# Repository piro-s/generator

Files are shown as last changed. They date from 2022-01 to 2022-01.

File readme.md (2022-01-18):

### generator  [OnHold]

#### Description device:  
The pulse generator, implemented on STM32, can generate:  
1. continuous pulse generation;  
2. generation of pulse bursts.  

Init mode:
- width - 1 us;  
- period - 10 us;  
- pack period - 100 us;  
- number of impulses - 5.  

Max number of impulses in package - 2048.  
Min pulse width 100 ns.  
Control from a computer via RS-232 (J8) interface or via UART-USB adapter (J6).  
The development of the device is suspended, the plans are:  
- firmware for analog channel;  
- saving data to a separate EEPROM (scheme and firmware);  
- firmware for LCD and keyboard;
- new version of the case.  

#### PC program description:
The program allows you to customize the set values for the generator.  
For use:  
- linux: run generator_pyGui.py  
- windows: run dist/generator_pyGui.exe  

Setup:  
1. Select the COM port to which the device is connected from the drop-down list:  
1_select  
2. By default, the generator runs in init mode. The current parameters are  
written in the current field. By pressing the button "Get parameters" you can  
get the current set values.  
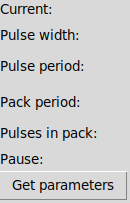
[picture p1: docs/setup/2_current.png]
2_current
  
If there is no data exchange with the generator, then there will be dashes in  
this field, there will also be errors in the log field.  
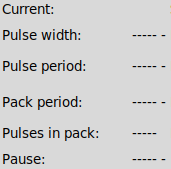
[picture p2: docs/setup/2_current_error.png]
2_current_error
  
3. The generator parameters are set in order, that is, the pulse duration and  
its period, the burst period (set in any case, even if not needed), the number  
of pulses are set separately, if the number of pulses is 0, then there will be  
a constant generation of pulses, without a burst.  
The name of the parameter is signed in the figure:  
3_setup  
If something is entered incorrectly, or some other error occurs, everything  
will be displayed in the log field.  
3_error  
4. If the wrong COM port was selected, then you can switch to the "Setup" tab,  
4_setup  
select "Disconnect", click "Refresh", select the required COM port from the  
drop-down list, and click the "Connect" button, you can go back to the  
"Impulse" tab.  

The protocol for data exchange between the device and the PC is  
[here](https://htmlpreview.github.io/?https://github.com/piro-s/generator/blob/master/docs/protocol.html).  

#### Scheme  
[scheme_v3.2_pdf](docs/scheme/scheme_v3.2.pdf)  

#### Case  
Prototype case for v3.2 generator board (case will fit next versions).  
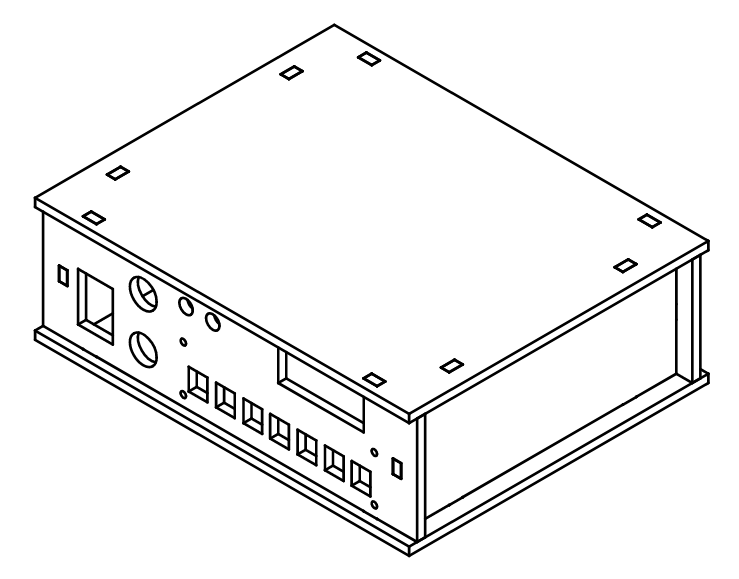
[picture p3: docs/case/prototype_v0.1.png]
prototype_v0_1
  
Errors:  
- the two diagonal posts interfere with the connectors.

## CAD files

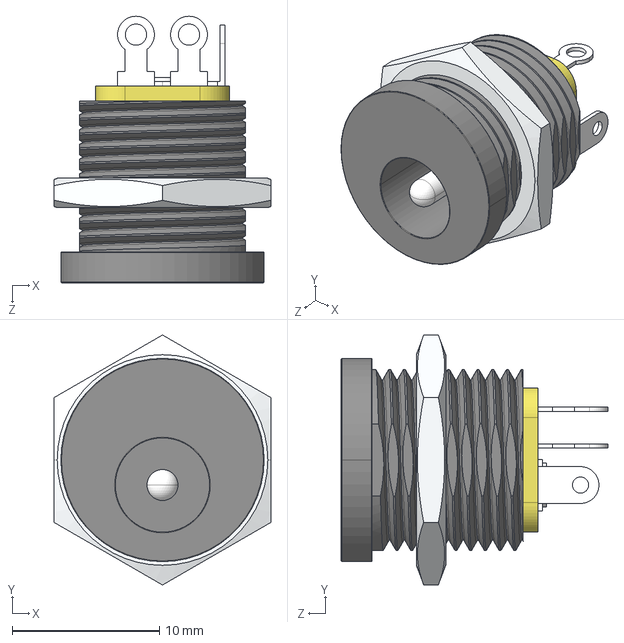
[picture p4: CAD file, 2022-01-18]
case/ASM, Adafruit 5.5 x 2.1 Coaxial DC Panel Mount Power Jack (PN 610).STEP
14.7 x 17.0 x 18.1 mm
Adafruit 5.5 x 2.1 DC Coax Panel Mount Power Jack (PN 601)_default
M12.5x1 Panel Nut_default

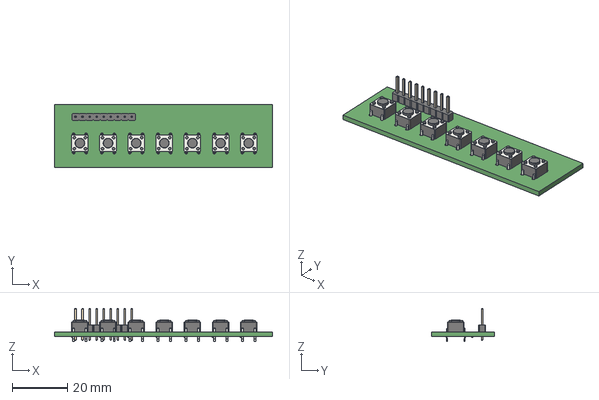
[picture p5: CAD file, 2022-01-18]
case/mini_keyboard.step
78.7 x 22.7 x 12.0 mm

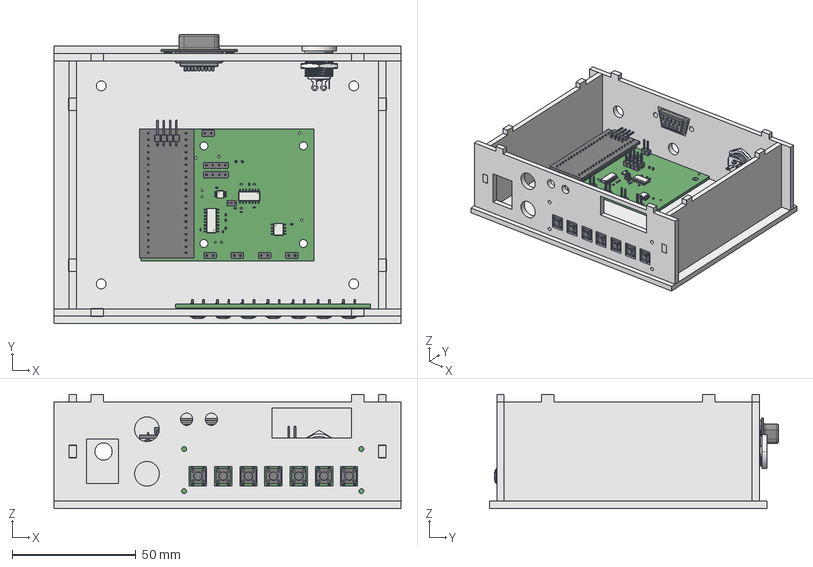
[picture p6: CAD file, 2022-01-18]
case/generator_v3.2.FCStd
140.0 x 116.7 x 46.0 mm
FRONT
RIGHT
BACK
LEFT
Adafruit 5.5 x 2.1 DC Coax Panel Mount Power Jack (PN 601)_default
M12.5x1 Panel Nut_default
D-Sub9 Female Connector with Solder Cups
BOTTOM

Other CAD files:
case/generator_v3.2.dxf

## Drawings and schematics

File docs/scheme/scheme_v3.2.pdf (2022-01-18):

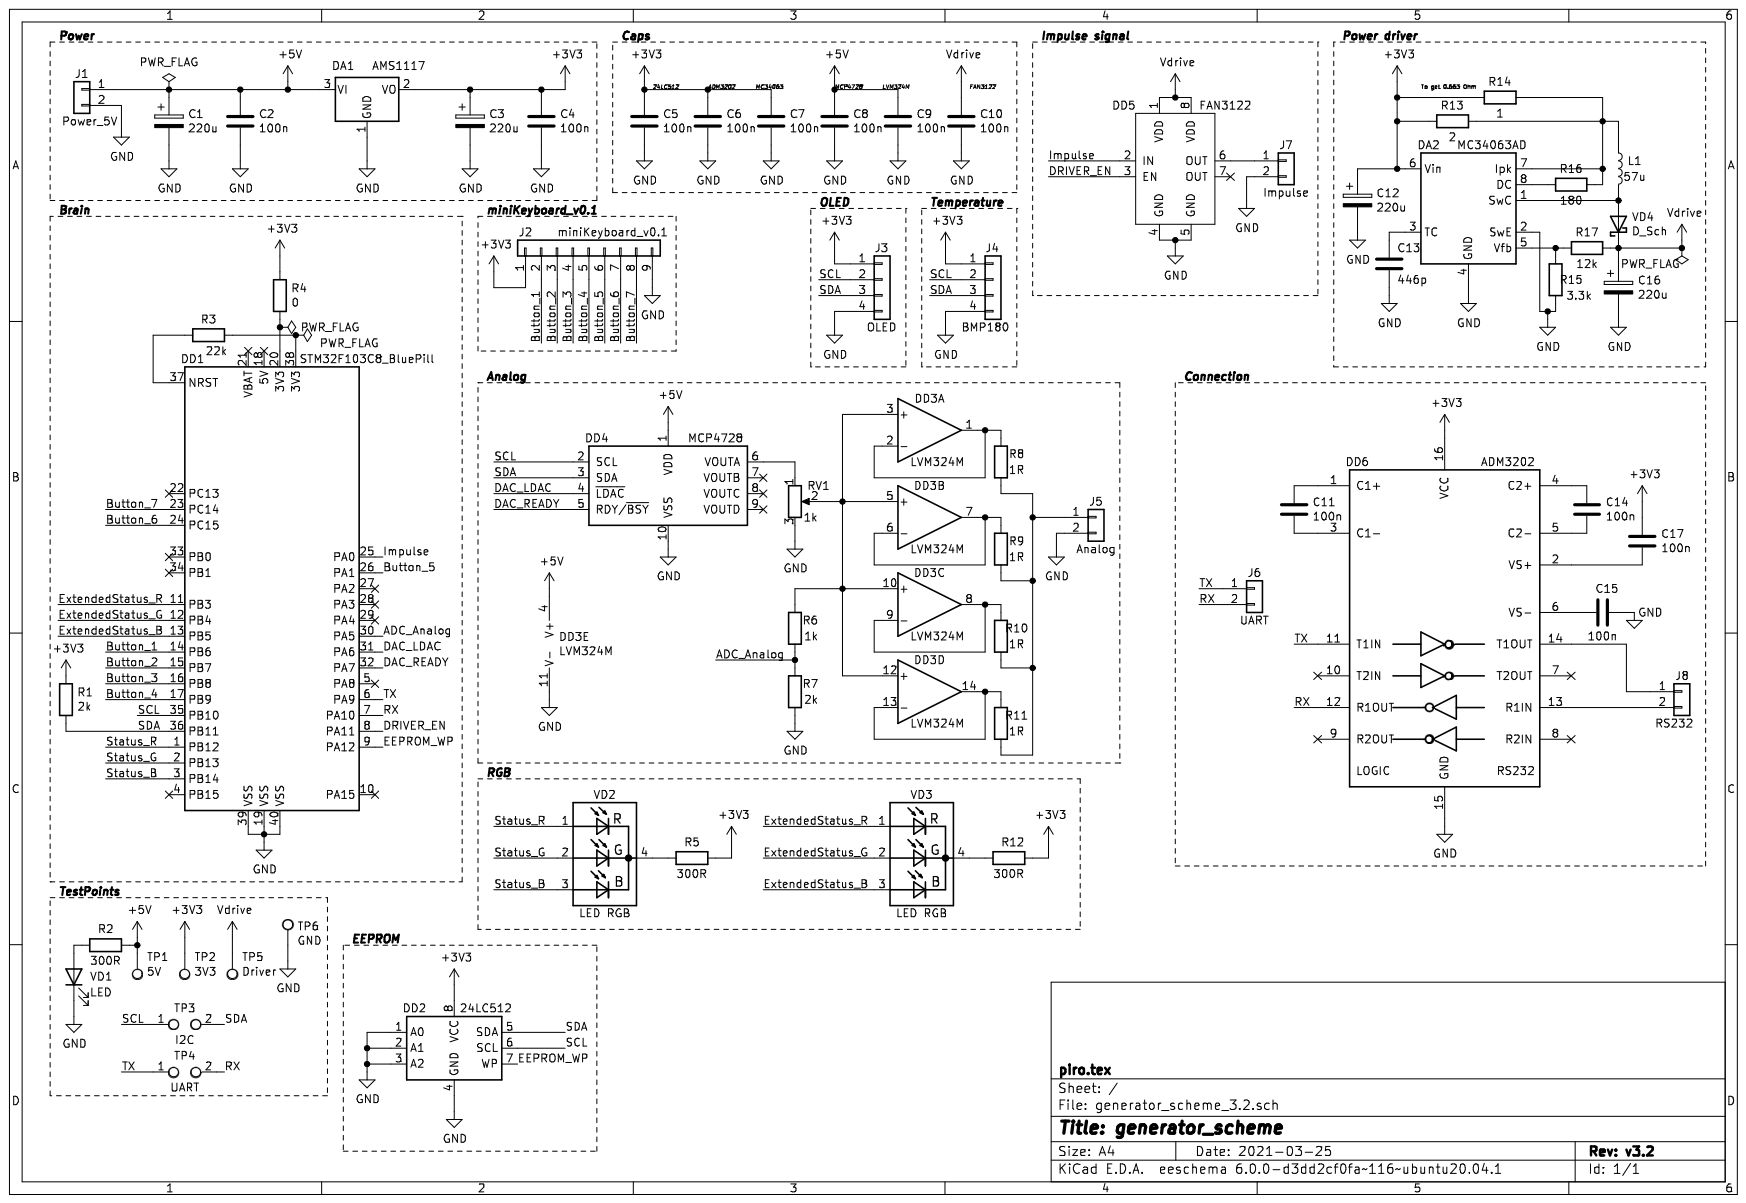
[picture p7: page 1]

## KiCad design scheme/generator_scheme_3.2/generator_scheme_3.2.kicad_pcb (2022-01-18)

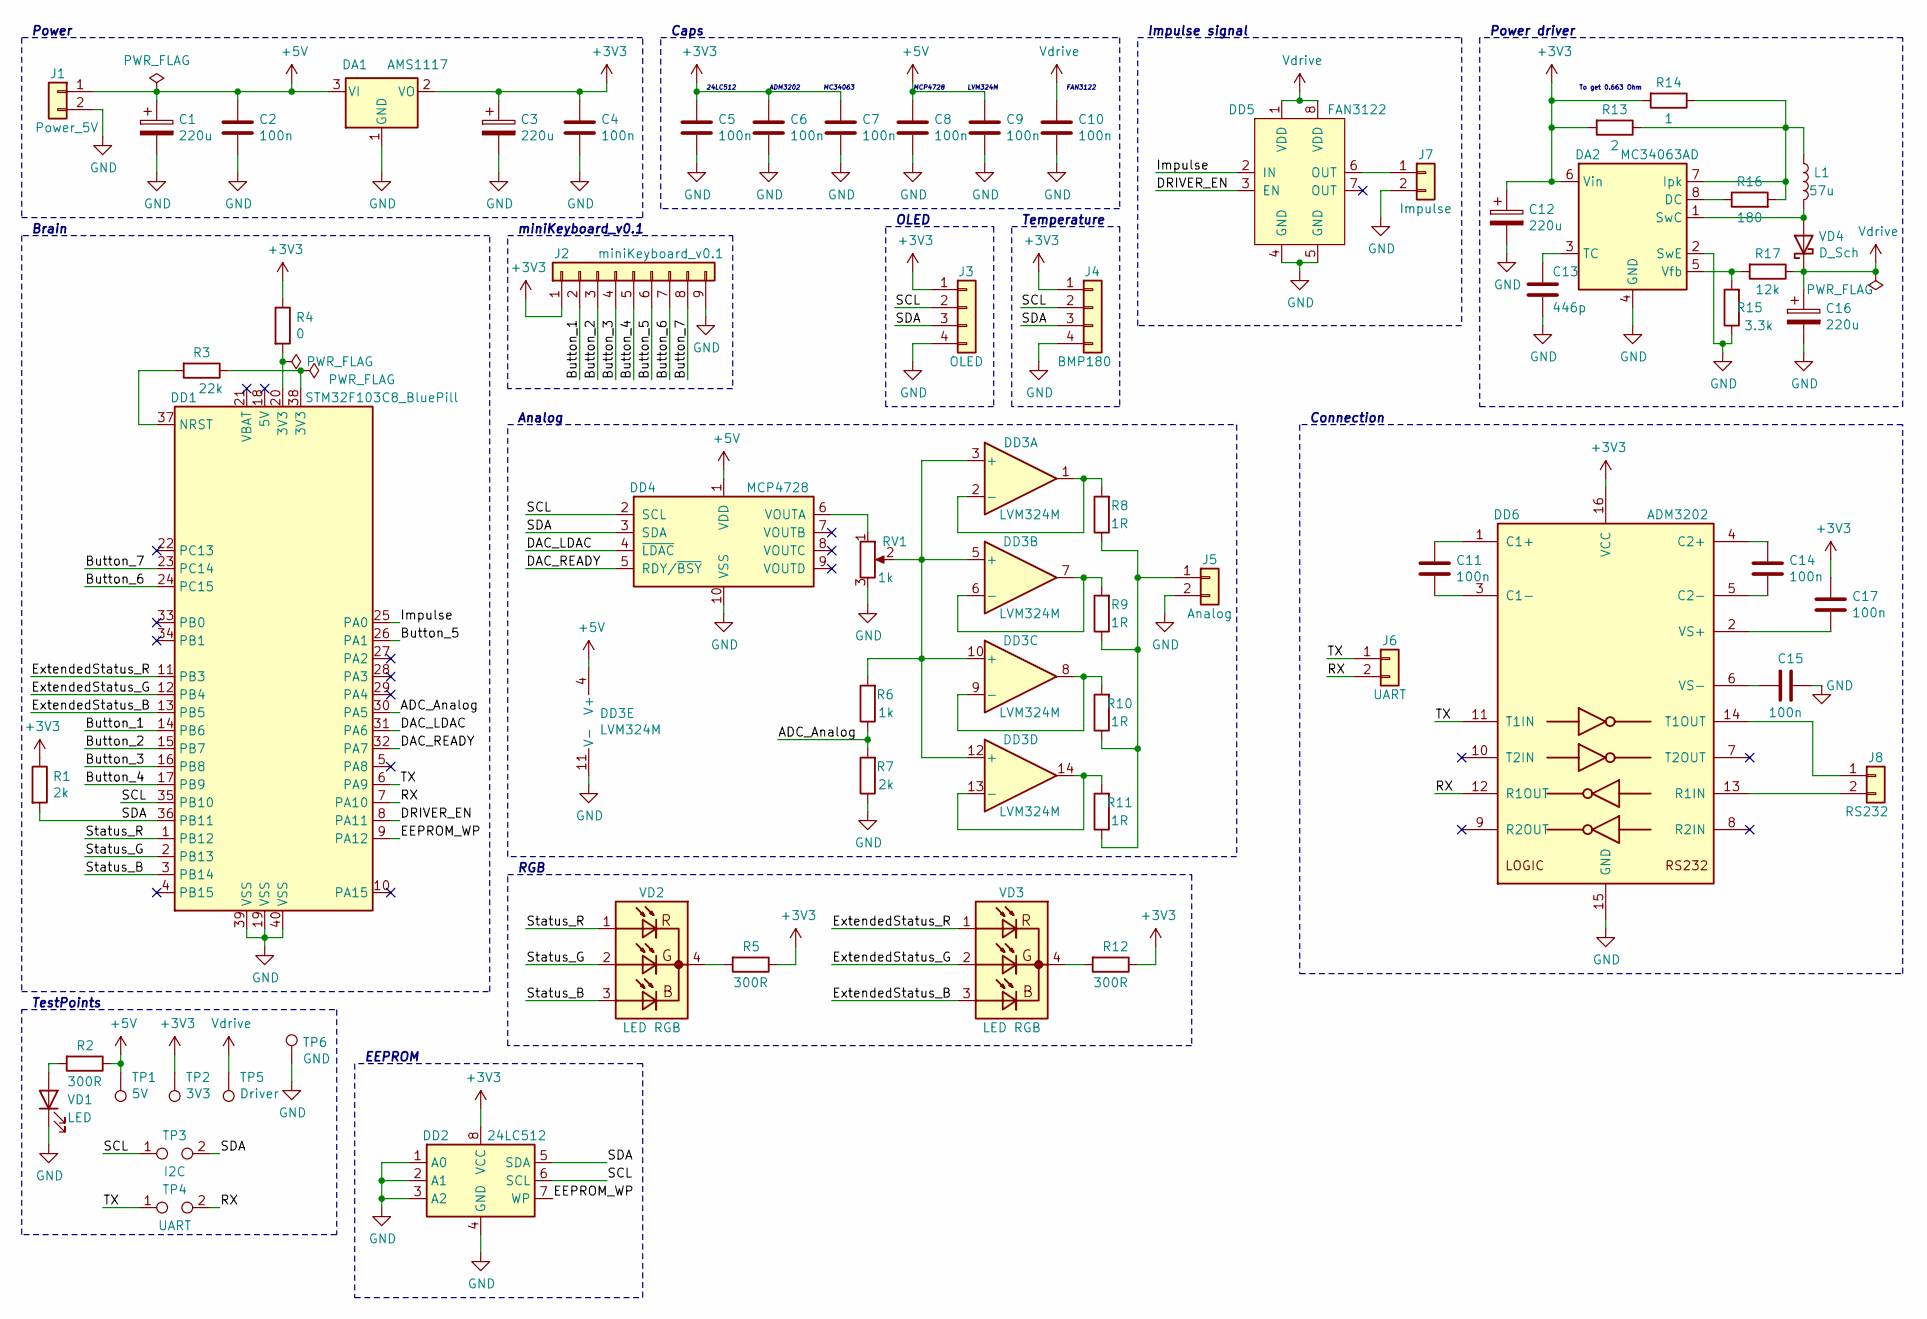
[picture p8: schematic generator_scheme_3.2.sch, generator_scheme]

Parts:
C1, C3, C12, C16: 220u; CP_EIA-7260-15_AVX-R_Pad2.68x6.30mm_HandSolder
C2, C4, C5, C6, C7, C8, C9, C10, C11, C14, C15, C17: 100n; C_0402_1005Metric
C13: 446p; C_0402_1005Metric
DA1: AMS1117; SOT-223-3_TabPin2
DA2: MC34063AD; SOIC-8_3.9x4.9mm_P1.27mm
DD1: STM32F103C8_BluePill
DD2: 24LC512; SOIC-8_3.9x4.9mm_P1.27mm
DD3: LVM324M; SOIC-14_3.9x8.7mm_P1.27mm
DD4: MCP4728; MSOP-10_3x3mm_P0.5mm
DD5: FAN3122; SOIC-8_3.9x4.9mm_P1.27mm
DD6: ADM3202; SO-16_3.9x9.9mm_P1.27mm
J1: Power_5V; PinHeader_1x02_P2.54mm_Vertical
J2: miniKeyboard_v0.1; PinSocket_1x09_P2.54mm_Vertical
J3: OLED; PinHeader_1x04_P2.54mm_Vertical
J4: BMP180; PinHeader_1x04_P2.54mm_Vertical
J5: Analog; PinHeader_1x02_P2.54mm_Vertical
J6: UART; PinHeader_1x02_P2.54mm_Vertical
J7: Impulse; PinHeader_1x02_P2.54mm_Vertical
J8: RS232; PinHeader_1x02_P2.54mm_Vertical
L1: 57u; L_7.3x7.3_H4.5
R1, R7: 2k; R_0402_1005Metric
R2, R5, R12: 300R; R_0402_1005Metric
R3: 22k; R_0402_1005Metric
R4: 0; R_0402_1005Metric
R6: 1k; R_0402_1005Metric
R8, R9, R10, R11: 1R; R_0402_1005Metric
R13: 2; R_0402_1005Metric
R14: 1; R_0402_1005Metric
R15: 3.3k; R_0402_1005Metric
R16: 180; R_0402_1005Metric
R17: 12k; R_0402_1005Metric
RV1: 1k; PinHeader_1x03_P1.27mm_Vertical
TP1: 5V; TestPoint_Keystone_5000-5004_Miniature
TP2: 3V3; TestPoint_Keystone_5000-5004_Miniature
TP3: I2C; TestPoint_2Pads_Pitch2.54mm_Drill0.8mm
TP4: UART; TestPoint_2Pads_Pitch2.54mm_Drill0.8mm
TP5: Driver; TestPoint_Keystone_5000-5004_Miniature
TP6: GND; TestPoint_Keystone_5000-5004_Miniature
VD1: LED; PinHeader_1x02_P2.54mm_Vertical
VD2, VD3: LED RGB; PinHeader_1x04_P1.27mm_Vertical
VD4: D_Sch; D_0603_1608Metric

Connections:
+3V3: C3.1, C4.1, C5.1, C6.1, C7.1, C12.1, C17.1, DA1.2 (VO), DA2.6 (Vin), DD2.8 (VCC), DD6.16 (VCC), J2.1, J3.1, J4.1, R1.1, R4.1, R5.1, R12.1, R13.2, R14.2, TP2.1
+5V: C1.1, C2.1, C8.1, C9.1, DA1.3 (VI), DD3.4 (V+), DD4.1 (VDD), J1.1, R2.1, TP1.1
/ADC_Analog: DD1.30 (PA5), R6.1, R7.2
/Button_1: DD1.14 (PB6), J2.2
/Button_2: DD1.15 (PB7), J2.3
/Button_3: DD1.16 (PB8), J2.4
/Button_4: DD1.17 (PB9), J2.5
/Button_5: DD1.26 (PA1), J2.6
/Button_6: DD1.24 (PC15), J2.7
/Button_7: DD1.23 (PC14), J2.8
/DAC_LDAC: DD1.31 (PA6), DD4.4 (~LDAC)
/DAC_READY: DD1.32 (PA7), DD4.5 (RDY/~BSY)
/DRIVER_EN: DD1.8 (PA11), DD5.3 (EN)
/EEPROM_WP: DD1.9 (PA12), DD2.7 (WP)
/ExtendedStatus_B: DD1.13 (PB5), VD3.3 (AB)
/ExtendedStatus_G: DD1.12 (PB4), VD3.2 (AG)
/ExtendedStatus_R: DD1.11 (PB3), VD3.1 (AR)
/Impulse: DD1.25 (PA0), DD5.2 (IN)
/RX: DD1.7 (PA10), DD6.12 (R1OUT), J6.2, TP4.2
/SCL: DD1.35 (PB10), DD2.6 (SCL), DD4.2 (SCL), J3.2, J4.2, TP3.1
/SDA: DD1.36 (PB11), DD2.5 (SDA), DD4.3 (SDA), J3.3, J4.3, R1.2, TP3.2
/Status_B: DD1.3 (PB14), VD2.3 (AB)
/Status_G: DD1.2 (PB13), VD2.2 (AG)
/Status_R: DD1.1 (PB12), VD2.1 (AR)
/TX: DD1.6 (PA9), DD6.11 (T1IN), J6.1, TP4.1
GND: C1.2, C2.2, C3.2, C4.2, C5.2, C6.2, C7.2, C8.2, C9.2, C10.2, C12.2, C13.2, C15.1, C16.2, DA1.1 (GND), DA2.2 (SwE), DA2.4 (GND), DD1.19 (VSS), DD1.39 (VSS), DD1.40 (VSS), DD2.1 (A0), DD2.2 (A1), DD2.3 (A2), DD2.4 (GND), DD3.11 (V-), DD4.10 (VSS), DD5.4 (GND), DD5.5 (GND), DD6.15 (GND), J1.2, J2.9, J3.4, J4.4, J5.2, J7.2, R7.1, R15.1, RV1.3, TP6.1, VD1.1 (K)
unnamed: C11.1, DD6.1 (C1+)
unnamed: C11.2, DD6.3 (C1-)
unnamed: C13.1, DA2.3 (TC)
unnamed: C14.1, DD6.4 (C2+)
unnamed: C14.2, DD6.5 (C2-)
unnamed: C15.2, DD6.6 (VS-)
unnamed: C17.2, DD6.2 (VS+)
unnamed: DA2.1 (SwC), L1.2, VD4.2 (A)
unnamed: DA2.5 (Vfb), R15.2, R17.2
unnamed: DA2.7 (Ipk), L1.1, R13.1, R14.1, R16.2
unnamed: DA2.8 (DC), R16.1
unnamed: DD1.20 (3V3), R4.2
unnamed: DD1.37 (NRST), R3.2
unnamed: DD1.38 (3V3), R3.1
unnamed: DD3.1, DD3.2 (-), R8.2
unnamed: DD3.6 (-), DD3.7, R9.2
unnamed: DD3.8, DD3.9 (-), R10.2
unnamed: DD3.3 (+), DD3.5 (+), DD3.10 (+), DD3.12 (+), R6.2, RV1.2
unnamed: DD3.13 (-), DD3.14, R11.2
unnamed: DD4.6 (VOUTA), RV1.1
unnamed: DD5.6 (OUT), J7.1
unnamed: DD6.13 (R1IN), J8.2
unnamed: DD6.14 (T1OUT), J8.1
unnamed: J5.1, R8.1, R9.1, R10.1, R11.1
unnamed: R2.2, VD1.2 (A)
unnamed: R5.2, VD2.4 (C)
unnamed: R12.2, VD3.4 (C)
Vdrive: C10.1, C16.1, DD5.1 (VDD), DD5.8 (VDD), R17.1, TP5.1, VD4.1 (K)

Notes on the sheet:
EEPROM
Power
To get 0.663 Ohm
Power driver
Brain
Connection
Impulse signal
ADM3202
24LC512
Temperature
RGB
MC34063
MCP4728
FAN3122
LVM324M
Analog
Caps
TestPoints
OLED
miniKeyboard_v0.1

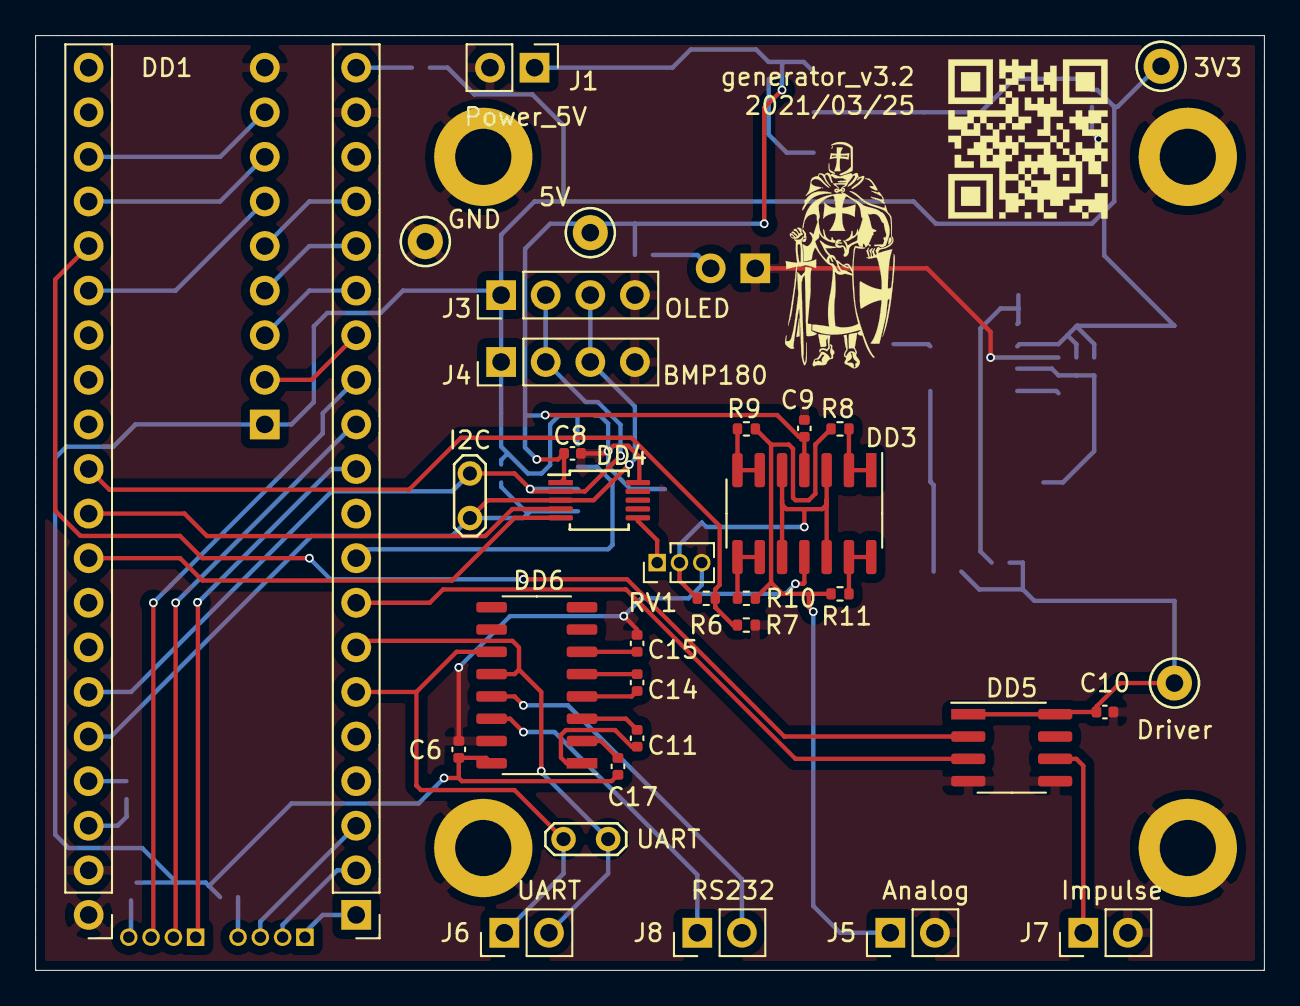
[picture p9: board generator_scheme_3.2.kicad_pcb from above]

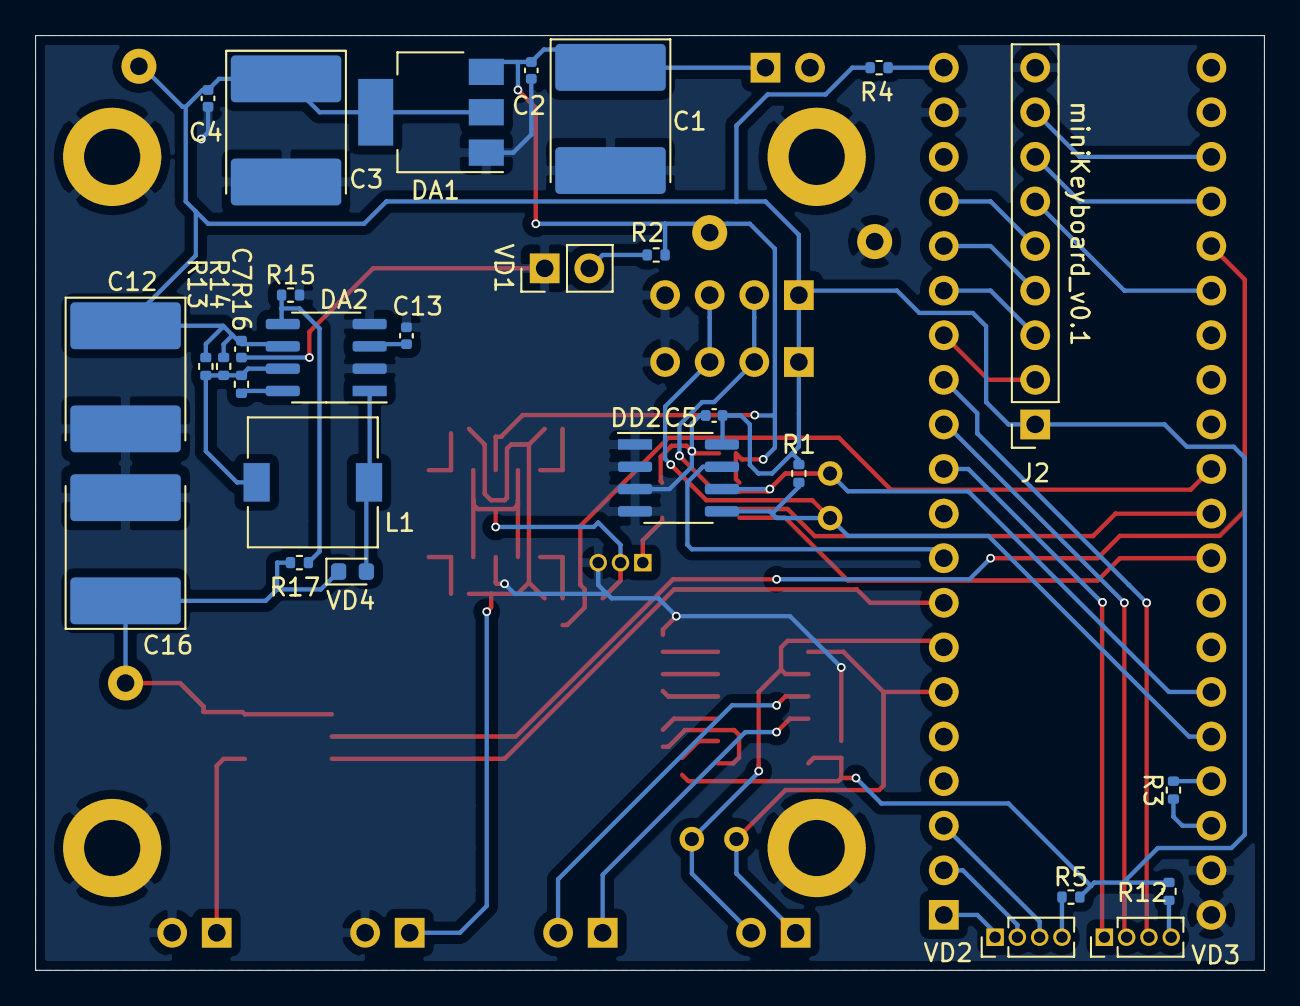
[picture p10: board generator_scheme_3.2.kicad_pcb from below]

Board: 2 copper layers, 70.0 x 53.2 mm, 62 parts (29 on the bottom side), 54 nets.

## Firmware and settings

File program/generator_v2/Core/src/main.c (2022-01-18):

/**
 *******************************************************************************
 * @file           : main.c
 * @author         : piro.tex
 * @brief          : Programmable generator - impulse & impulse packs, analog,
 * mode set in program on PC. Value in TIM set for f=72 MHz.
 * Max number of impulses in package - 2048.
 * Min pulse width 100 ns.
 *
 * Init mode:
 * - width - 1 us;
 * - period - 10 us;
 * - pack period - 100 us;
 * - number of impulses - 5.
 *
 * Periphery:
 * - TIM2 - PWM 3 channel - pulse length and period;
 * - TIM3 - start TIM2 - pack period;
 * - TIM4 - 1 ms dispatcher;
 * - DMA - 1 channel for TIM2 PWM channel 3;
 * - UART1 - 115200;
 * - I2C2 - for DAC & BMP180.
 *
 *******************************************************************************
**/


///--- #include
#include "stm32f1xx.h"

//#include "../inc/i2c.h"
#include "../inc/uart.h"

//#include "../inc/mcp4728.h"
//#include "../inc/ssd1306.h"

#include "../inc/tools.h"
#include "../inc/generator.h"
#include "../inc/protocol.h"
#include "../inc/dispatcher.h"


///--- initializations
void Init_TIM(void); // Init timers
void Init_DMA(void); // Init DMA
void Init_Struct(void); // Init structs


///--- handlers


///--- functions


///--- enum's


///--- struct


///--- constants


///--- counters


///--- flags                // for all flags state_on - set; state_off - reset


///--- varibles


///--- generator init value
uint16_t u16_packPeriod = 100 * 72 - 1; // Package period - 100 us (Init value)
uint16_t u16_pulseN = 5; // Size transmit package in DMA (number of impulses in package)
uint16_t u16_pulseWidth = 1 * 72 - 2; // Pulse width - 1 us (Init value)
uint16_t u16_pulsePeriod = 10 * 72 - 1; // Pulse period - 10 us (Init value)

uint8_t u8_packPeriodMltpl = 'u'; // Package period multiplier (us - init value)
uint8_t u8_pulseWidthMltpl = 'u'; // Pulse width multiplier (us - init value)
uint8_t u8_pulsePeriodMltpl = 'u'; // Pulse period multiplier (us - init value)

uint16_t u16_pack_psc = 0; // Prescaler for pack period
uint16_t u16_pulse_psc = 0; // Prescaler for pulse period

uint8_t u8_state_pack = state_pack; // State - pack or inf


///--- variables struct


///--- setters/getters



int main(void)
{
    //--- Core
    SetSysClockTo72(); // Set f = 72 MHz
    SystemCoreClockUpdate(); // Update core clock (necessary)


    //--- Periphery
    ///////////////////////// TODO led for error
    uart_Init(uart_UART1, 115200, uart_RXNEIE, uart_TXEIE_n);


    //--- Init
    Init_TIM(); // Init timers
    Init_DMA(); // Init DMA
    Init_Struct(); // Init structs
    //Init_LED(); // Init LED


    //--- Start
    clear_uartRecData(); // Clear uart receive data, counters and flags
    clear_uartTrData(); // Clear uart transmit data

    //LED(LED_OFF, LED_OFF); // Turn off all LED
    //LED(LED_ON, LED_COLOR_GREEN); // Turn on green LED

    start_Generator_Impulse(); // Start generator in init mode

    while(1)
    {
        dispatcher(); // Dispatcher
    } // while(1

} // int main(void)


//***
//------------------------------------------------------------------------------
//***


///--- initializations
void Init_TIM(void) // Init timers
{
    //--- TIM2 set us PWM channel 3 - for impulses -----------------------------
    //--- TIM3 set for start TIM2 - for impulse packages -----------------------
    //--- TIM4 set for 1 ms count ----------------------------------------------

    //--- Set TIM2
    RCC->APB1ENR |= RCC_APB1ENR_TIM2EN; // RCC TIM2
    RCC->APB2ENR |= RCC_APB2ENR_IOPAEN; // RCC Port A (PA2 - TIM2 Channel 3)

    GPIOA->CRL |= GPIO_CRL_CNF2_1; // Set PA2 as output and alter mode
    GPIOA->CRL &= ~GPIO_CRL_CNF2_0; // Set PA2 as output and alter mode
    GPIOA->CRL |= GPIO_CRL_MODE2; // Set front 50MHz

    TIM2->CCER = 0; // Reset CCER
    TIM2->PSC = u16_pulse_psc; // Without prescale (1 tick = 1 / f,  72 ticks - 1us)
    TIM2->ARR = u16_pulsePeriod; // Impulse period in ticks


    TIM2->CCR3 = u16_pulseWidth; // Pulse width in ticks
    TIM2->CCMR2 |= (TIM_CCMR2_OC3M_1 | TIM_CCMR2_OC3M_2); // 110: PWM mode 1
    TIM2->CCMR2 &= ~TIM_CCMR2_OC3M_0; // 110: PWM mode 1
    TIM2->CCER |= TIM_CCER_CC3E; // Set signal us output (output contorl enable)

    //--- Set DMA in TIM2
    TIM2->DIER |= TIM_DIER_UIE; // Enable interrupt from event
    TIM2->DIER |= TIM_DIER_CC3DE; // Enable request from DMA
    TIM2->CCMR2 |= TIM_CCMR2_OC3PE; // Enable preload


    //--- Set TIM3
    RCC->APB1ENR |= RCC_APB1ENR_TIM3EN; // RCC TIM3

    TIM3->PSC = u16_pack_psc; // Without prescale (1 tick = 1 / f,  72 ticks - 1us)
    TIM3->ARR = u16_packPeriod; // Impulse package period in ticks

    TIM3->DIER |= TIM_DIER_UIE; // Enable interrupt from overload
    NVIC_EnableIRQ(TIM3_IRQn); // Enable handler interrupt TIM3


    //--- Set TIM4
    RCC->APB1ENR |= RCC_APB1ENR_TIM4EN; // RCC TIM4

    TIM4->PSC = 72 - 1; // Prescaler (1 tick = 1 us)
    TIM4->ARR = 1000; // 1 ms - period in ticks
    TIM4->DIER |= TIM_DIER_UIE; // Enable interrupt from overload
    TIM4->CR1 |= TIM_CR1_CEN; // Enable TIM4
    NVIC_EnableIRQ(TIM4_IRQn); // Enable handler interrupt TIM4

    return;
} // Init_TIM

void Init_DMA(void) // Init DMA
{
    //--- DMA set channel 1 for TIM2 Channel 3 ---------------------------------
    for(uint16_t it = 0; it < size_buffer_DMA; it++)
        dataToSendDMA[it] = u16_pulseWidth; // Pulse width in ticks

    RCC->AHBENR |= RCC_AHBENR_DMA1EN; // RCC DMA1

    DMA1_Channel1->CCR |= (DMA_CCR_TCIE | DMA_CCR_TEIE); // Interrupt for complete transmit or error
    DMA1_Channel1->CCR |= DMA_CCR_DIR; // Direction - from memory to periphery
    DMA1_Channel1->CCR |= DMA_CCR_CIRC; // Cycle transmit
    DMA1_Channel1->CCR |= DMA_CCR_MINC; // Memory increment mode
    DMA1_Channel1->CCR |= DMA_CCR_PSIZE_0; // Receive data - 16 bit
    DMA1_Channel1->CCR |= DMA_CCR_MSIZE_1; // Transmit data - 32 bit

    DMA1_Channel1->CNDTR = u16_pulseN; // Size tranmit package
    DMA1_Channel1->CPAR = (uint32_t)&(TIM2->CCR3); // Address periphery
    DMA1_Channel1->CMAR = (uint32_t)dataToSendDMA; // Address buffer in memory

    NVIC_EnableIRQ(DMA1_Channel1_IRQn); // Enable interrupt for DMA

    return;
} // void Init_DMA(void)

void Init_Struct(void) // Init struct
{
    generator_impulse.pulseWidth = u16_pulseWidth;
    generator_impulse.pulsePeriod = u16_pulsePeriod;
    generator_impulse.pulseN = u16_pulseN;
    generator_impulse.packPeriod = u16_packPeriod;

    generator_impulse.packPeriodMltpl = u8_packPeriodMltpl;
    generator_impulse.pulseWidthMltpl = u8_pulseWidthMltpl;
    generator_impulse.pulsePeriodMltpl = u8_pulsePeriodMltpl;

    generator_impulse.pulse_psc = u16_pulse_psc; // Prescaler for pulse period
    generator_impulse.pack_psc = u16_pack_psc; // Prescaler for package period

    generator_impulse.state_pack = u8_state_pack;
    generator_impulse.state_generation = state_on;

    copy_Generator_Impulse(&generator_impulse, &generator_impulse_rec);

    return;
} // Init_Struct


//***
//------------------------------------------------------------------------------
//***


///--- handlers


//***
//------------------------------------------------------------------------------
//***


//***
//------------------------------------------------------------------------------
//***


///--- functions


//**------------------------------------------------------------------------**//
//**------------------------------------------------------------------------**//
//**------------------------------------------------------------------------**//

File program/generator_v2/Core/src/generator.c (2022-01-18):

/**
 * @file generator_impulse.c
 *
 *
 * @Created: 16.01.2021 ‏‎9:11:10
 * @Author : piro.tex
 */

///--- include's
#include "../inc/generator.h"


///--- variables struct
gen_imp generator_impulse; // Current
gen_imp generator_impulse_rec; // For receive from PC


///--- variables


///--- buffers
uint16_t dataToSendDMA[size_buffer_DMA]; // Buffer for DMA


///--- handlers
void TIM3_IRQHandler(void) // Handler interrupt TIM3
{
    // Set out as high and start pulse
    TIM2->CR1 |= TIM_CR1_CEN; // Enable TIM2
    DMA1_Channel1->CCR |= DMA_CCR_EN; // Enable DMA

    TIM3->SR &= ~TIM_SR_UIF; // Clear bit interrupt

    return;
} // TIM3_IRQHandler

void DMA1_Channel1_IRQHandler(void) // Handler DMA1
{
    if(DMA1->ISR & DMA_ISR_TCIF1) // If tranmit complete
    {
        if(generator_impulse.state_pack == state_pack) // If pulses not infinite
        {
            TIM2->CR1 &= ~TIM_CR1_CEN; // Stop TIM2
            DMA1_Channel1->CCR &= ~DMA_CCR_EN; // Disable DMA
        } // if(generator_impulse.state_pack == state_pack)

        DMA1->IFCR = DMA_IFCR_CTCIF1; // Clear interrupt flag
    } // if(DMA1->ISR & DMA_ISR_TCIF1)

    return;
} // DMA1_Channel1_IRQHandler


//***
//------------------------------------------------------------------------------
//***


///--- impulse generator functions()
void change_Generator_Impulse(void) // Change generator mode
{
    stop_Generator_Impulse(); // Stop all generator timers
    set_Generator_Impulse(); // Setting generator timers
    start_Generator_Impulse(); // Start all generator timers

    return;
} // void change_Generator_Impulse(void)

void stop_Generator_Impulse(void) // Stop all generator timers
{
    DMA1_Channel1->CCR &= ~DMA_CCR_EN; // Disable DMA
    TIM2->CCMR2 &= ~TIM_CCMR2_OC3M_1; // 100: Force inactive TIM2
    TIM2->CR1 &= ~TIM_CR1_CEN; // Disable TIM2
    TIM3->CR1 &= ~TIM_CR1_CEN; // Disable TIM3

    return;
} // void stop_Generator_Impulse(void)

void set_Generator_Impulse(void) // Setting timers
{
    // Set pulse parameters
    TIM2->PSC = generator_impulse.pulse_psc;
    TIM2->ARR = generator_impulse.pulsePeriod;
    TIM3->PSC = generator_impulse.pack_psc;
    TIM3->ARR = generator_impulse.packPeriod;
    DMA1_Channel1->CNDTR = generator_impulse.pulseN; // Number of pulses in package

    for(uint16_t it = 0; it < size_buffer_DMA; it++)
        dataToSendDMA[it] = generator_impulse.pulseWidth; // Pulse width in ticks

    return;
} // void set_Generator_Impulse(void)

void start_Generator_Impulse(void) // Start all generator timers
{
    TIM3->CR1 |= TIM_CR1_CEN; // Enable TIM3
    TIM2->CCMR2 |= TIM_CCMR2_OC3M_1; // 110: PWM mode 1
    TIM2->CR1 |= TIM_CR1_CEN; // Enable TIM2
    DMA1_Channel1->CCR |= DMA_CCR_EN; // Enable DMA

    return;
} // void start_Generator_Impulse(void)

void copy_Generator_Impulse(gen_imp* from, gen_imp* to) // Copy parameters generator
{
    to->pulseWidth = from->pulseWidth;
    to->pulsePeriod = from->pulsePeriod;
    to->pulseN = from->pulseN;
    to->packPeriod = from->packPeriod;

    to->packPeriodMltpl = from->packPeriodMltpl;
    to->pulseWidthMltpl = from->pulseWidthMltpl;
    to->pulsePeriodMltpl = from->pulsePeriodMltpl;

    to->pulse_psc = from->pulse_psc;
    to->pack_psc = from->pack_psc;

    to->state_pack = from->state_pack;
    to->state_generation = from->state_generation;

    return;
} // void copy_Generator_Impulse(generator_impulse* from, generator_impulse* to)

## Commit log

2022-01-18 Device program
    generator_v2
2022-01-18 Scheme
    scheme for v3.2
    [generator_scheme_3.2.kicad_pcb, generator_scheme_3.2.sch]
2022-01-18 docs: PC program
    added protocol between device and PC
2022-01-18 Case
    added case prototype
    [ASM, Adafruit 5.5 x 2.1 Coaxial DC Panel Mount Power Jack (PN 610).STEP, generator_v3.2.FCStd, generator_v3.2.dxf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]
